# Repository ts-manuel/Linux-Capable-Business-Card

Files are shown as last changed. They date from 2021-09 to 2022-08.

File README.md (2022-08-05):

# Linux Capable business Card
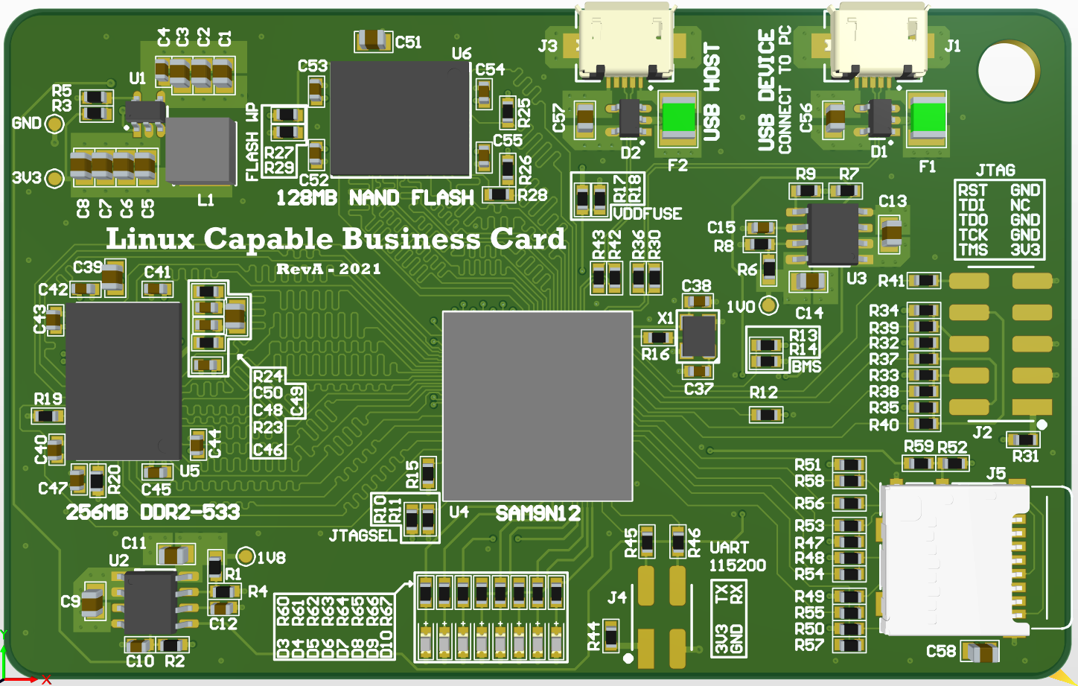
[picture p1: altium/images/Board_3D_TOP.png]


<!-- TABLE OF CONTENTS -->
<details open="open">
  <summary>Table of Contents</summary>
  <ol>
    <li><a href="#about-the-project">About The Project</a></li>
    <li><a href="#block-diagram">Block Diagram</a></li>
    <li><a href="#getting-started">Block Diagram</a></li>
  </ol>
</details>

<!-- ABOUT THE PROJECT -->
## About The Project
Business card sized computer capable of running Linux.

- Microchip AT91SAM9N12 microprocessor, ARM926 core running at 400MHz
- 256MB RAM DDR2-533
- 128MB of NAND FLASH
- micro SD-Card slot
- 8x LEDs

For more info check out the [project on hackaday.io](https://hackaday.io/project/181259-linux-capable-business-card)

<!-- BLOCK DIAGRAM -->
## Block Diagram
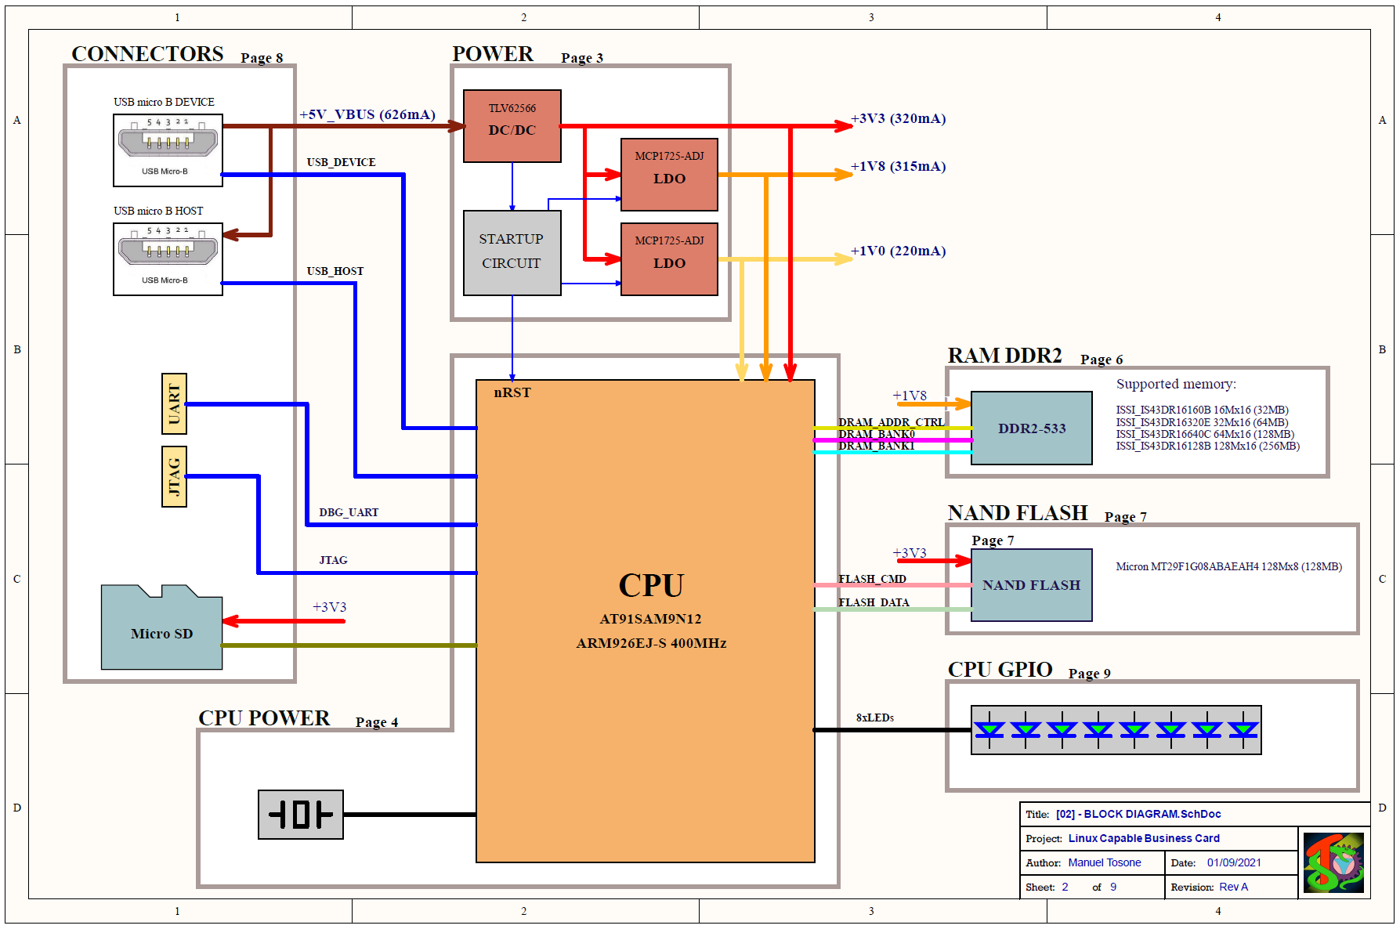
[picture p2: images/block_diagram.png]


<!-- GETTING STARTED -->
## Getting Started
### Getting the code
    git clone --recursive https://github.com/ts-manuel/Linux-Capable-Business-Card.git

### Compinig
    cd linux
    ./setup.sh
    ./build_sd_linux_dt.sh

### Buildroot Folder Structure
- buildroot/output/build/     where pakages are downloaded and builded
- buildroot/output/images/    where images are copied after building

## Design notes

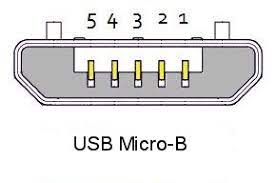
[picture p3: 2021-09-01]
altium/images/USB_micro_B.jpg

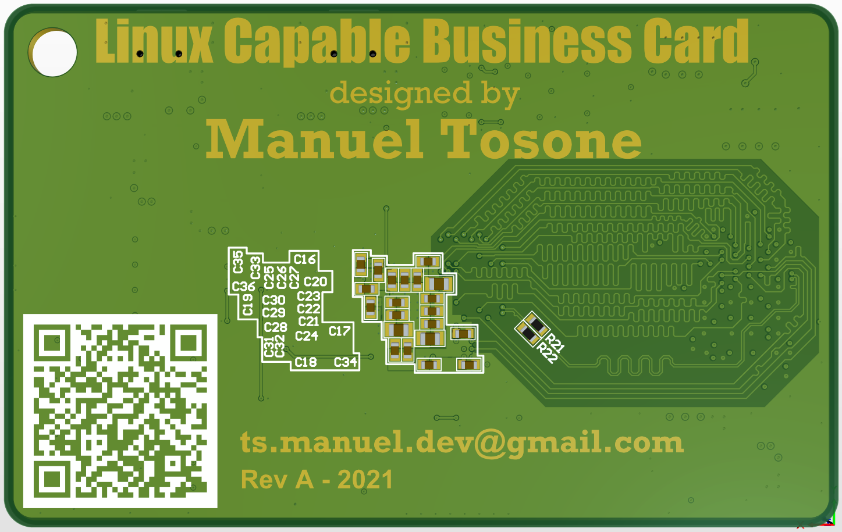
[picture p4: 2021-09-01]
altium/images/Board_3D_BOTTOM.png

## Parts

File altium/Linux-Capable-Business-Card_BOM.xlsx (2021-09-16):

Bill of Materials
Linux Capable Business Card - Rev A
# | Description | Supplier Part Number | Quantity | Designator | Value
1 | Multilayer Ceramic Capacitors MLCC - SMD/SMT WCAP-CSGP 4.7uF 0805 20% 16V MLCC | 710-885012107013 | 20 | C1, C2, C3, C5, C6, C7, C8, C9, C11, C13, C14, C20, C24, C28, C39, C49, C51, C56, C57, C58 | 4.7uF
2 | Multilayer Ceramic Capacitors MLCC - SMD/SMT 16V 0.1uF X7R 0603 20% | 80-C0603C104M4RAC | 34 | C4, C10, C16, C17, C18, C19, C21, C22, C23, C25, C26, C27, C29, C30, C31, C32, C33, C34, C35, C36, C40, C41, C42, C43, C44, C45, C46, C47, C48, C50, C52, C53, C54, C55 | 100nF
3 | Multilayer Ceramic Capacitors MLCC - SMD/SMT 50V 1000pF X7R 0603 5% | 80-C0603C102J5R | 2 | C12, C15 | 1nF
4 | Multilayer Ceramic Capacitors MLCC - SMD/SMT WCAP-CSGP 33pF 0603 5% 50V MLCC | 710-885012006054 | 2 | C37, C38 | 33pF
5 | ESD Suppressors / TVS Diodes 2 Ch TVS Diode Array 3.3V 6.0A 400mW | 621-D1213A-02SM-7 | 2 | D1, D2
6 | Standard LEDs - SMD WL-SMCW SMDMono TpVw Waterclr 0603 BrtGrn | 710-150060VS75000 | 8 | D3, D4, D5, D6, D7, D8, D9, D10 | Green
7 | Resettable Fuses - PPTC Fuse | 530-0ZCH0050FF2G | 2 | F1, F2 | 500mA
8 | USB Connectors Micro B, USB 2.0, 1.8 A, Right Angle, Surface Mount (SMT), USB Receptacle | 490-UJ2-MIBH-G-SMTTR | 2 | J1, J3
9 | Headers & Wire Housings ECONOSTIK HEADER DR VT SMT 2X5 | 649-1012938391002ALF | 1 | J2
10 | Headers & Wire Housings ECONOSTIK HEADER DR VT SMT 2X2 | 649-1012938390401ALF | 1 | J4
11 | Memory Card Connectors MICRO SD PUSH-PULL SMT 1.42MM HEIGHT | 538-104031-0811 | 1 | J5
12 | Fixed Inductors 5020 2.2uH 42mOhms +/-30%Tol 2900mA | 963-NRS5020T2R2NMGJ | 1 | L1 | 2.2uH
13 | Thin Film Resistors - SMD 1/10W 412K ohm 1% 50ppm | 603-RT0603FRE07412KL | 1 | R1 | 412K
14 | Thin Film Resistors - SMD 1/10W 120K ohm 1% 50ppm | 603-RT0603FRE07120KL | 18 | R2, R4, R5, R7, R8, R9, R25, R26, R32, R33, R34, R35, R47, R48, R49, R50, R51, R52 | 120K
15 | Thin Film Resistors - SMD 1/10W 536K ohm 1% 50ppm | 603-RT0603FRE07536KL | 1 | R3 | 536K
16 | Thin Film Resistors - SMD 1/10W 174K ohm 1% 50ppm | 603-RT0603FRE07174KL | 1 | R6 | 174K
17 | Thin Film Resistors - SMD 1/10W 330 ohm 1% 50ppm | 603-RT0603FRD07330RL | 25 | R10, R11, R12, R13, R14, R15, R16, R17, R18, R19, R20, R23, R24, R27, R29, R45, R46, R60, R61, R62, R63, R64, R65, R66, R67 | 330R
18 | Thin Film Resistors - SMD 1/10W 27 ohm 1% 50ppm | 603-RT0603DRD0727RL | 21 | R21, R22, R28, R30, R31, R36, R37, R38, R39, R40, R41, R42, R43, R44, R53, R54, R55, R56, R57, R58, R59 | 27R
19 | TLV6256x 1.5-A High Efficiency Step-Down Converters in SOT-23 5-Pin Package | 595-TLV62566DBVR | 1 | U1
20 | 500 mA, Low Voltage, Low Quiescent Current LDO Regulator | 579-MCP1725-ADJE/SN | 2 | U2, U3
21 | MPU ARM926EJ-S 400MHz | 556-AT91SAM9N12-CU | 1 | U4
22 | 256Mx8, 128Mx16 DDR2 DRAM | 870-3DR16128C-25DBLI | 1 | U5
23 | NAND Flash SLC 1G 128MX8 VFBGA-63 | 340-139663-TRAY | 1 | U6
24 | Crystals 12MHz 20ppm 18pF -20C +70C | 520-120-18-33-JEMT | 1 | X1 | 12 MHz

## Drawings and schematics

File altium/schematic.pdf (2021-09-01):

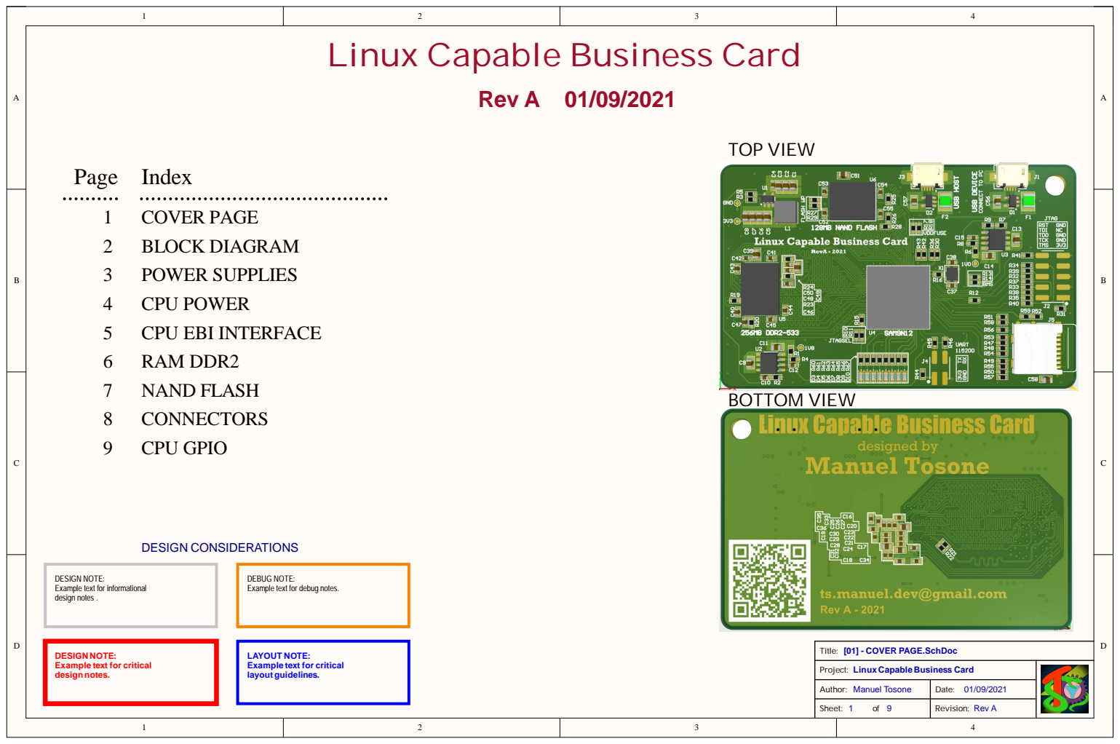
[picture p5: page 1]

Linux Capable Business Card

DESIGN NOTE:
Example text for informational
design notes .

DEBUG NOTE:
Example text for debug notes.

Example text for critical
design notes.

LAYOUT NOTE:
layout guidelines.

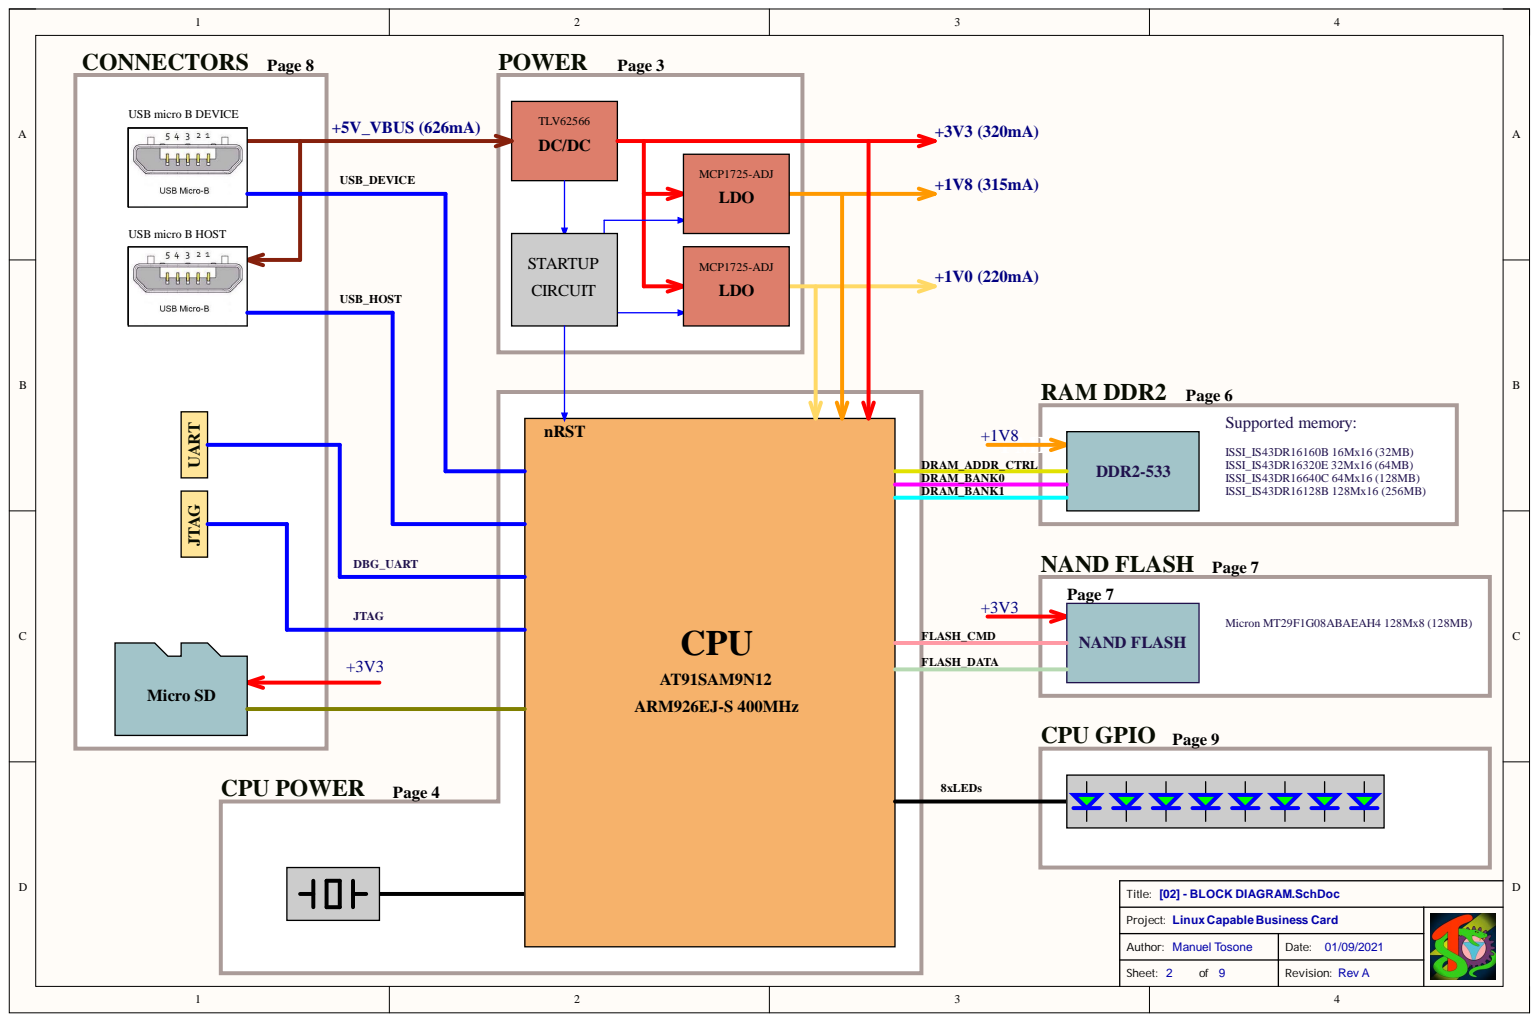
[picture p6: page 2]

USB_DEVICE

USB_HOST

DRAM_BANK0
DRAM_BANK1

Linux Capable Business Card

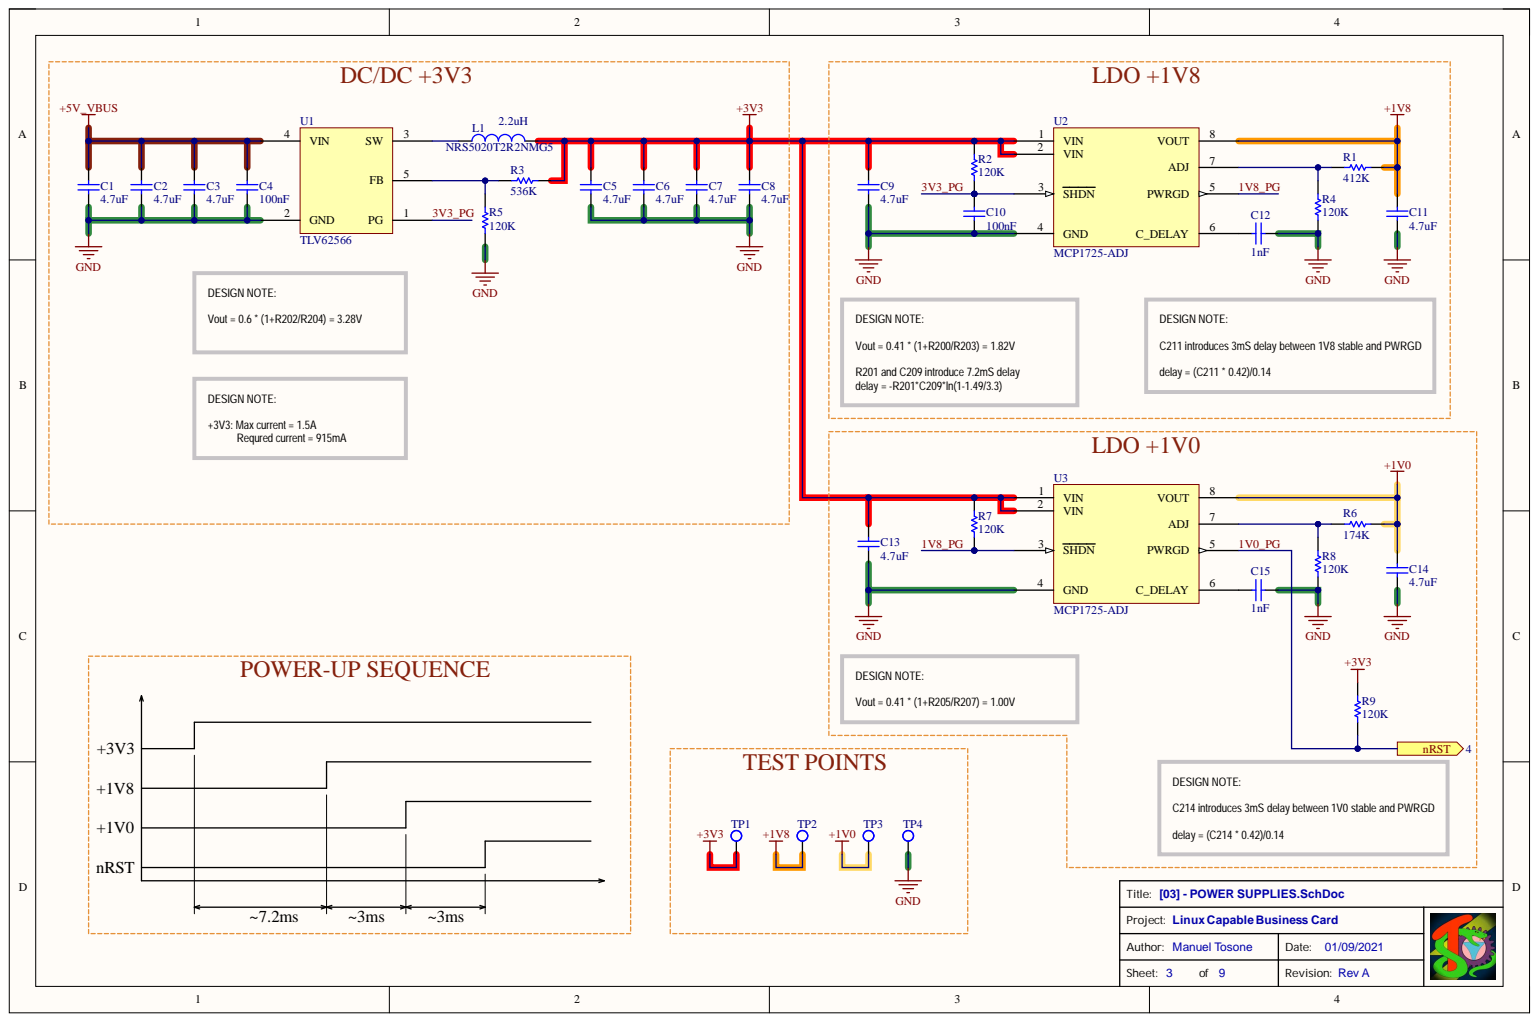
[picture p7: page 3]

C211 introduces 3mS delay between 1V8 stable and PWRGD

C214 introduces 3mS delay between 1V0 stable and PWRGD

Linux Capable Business Card

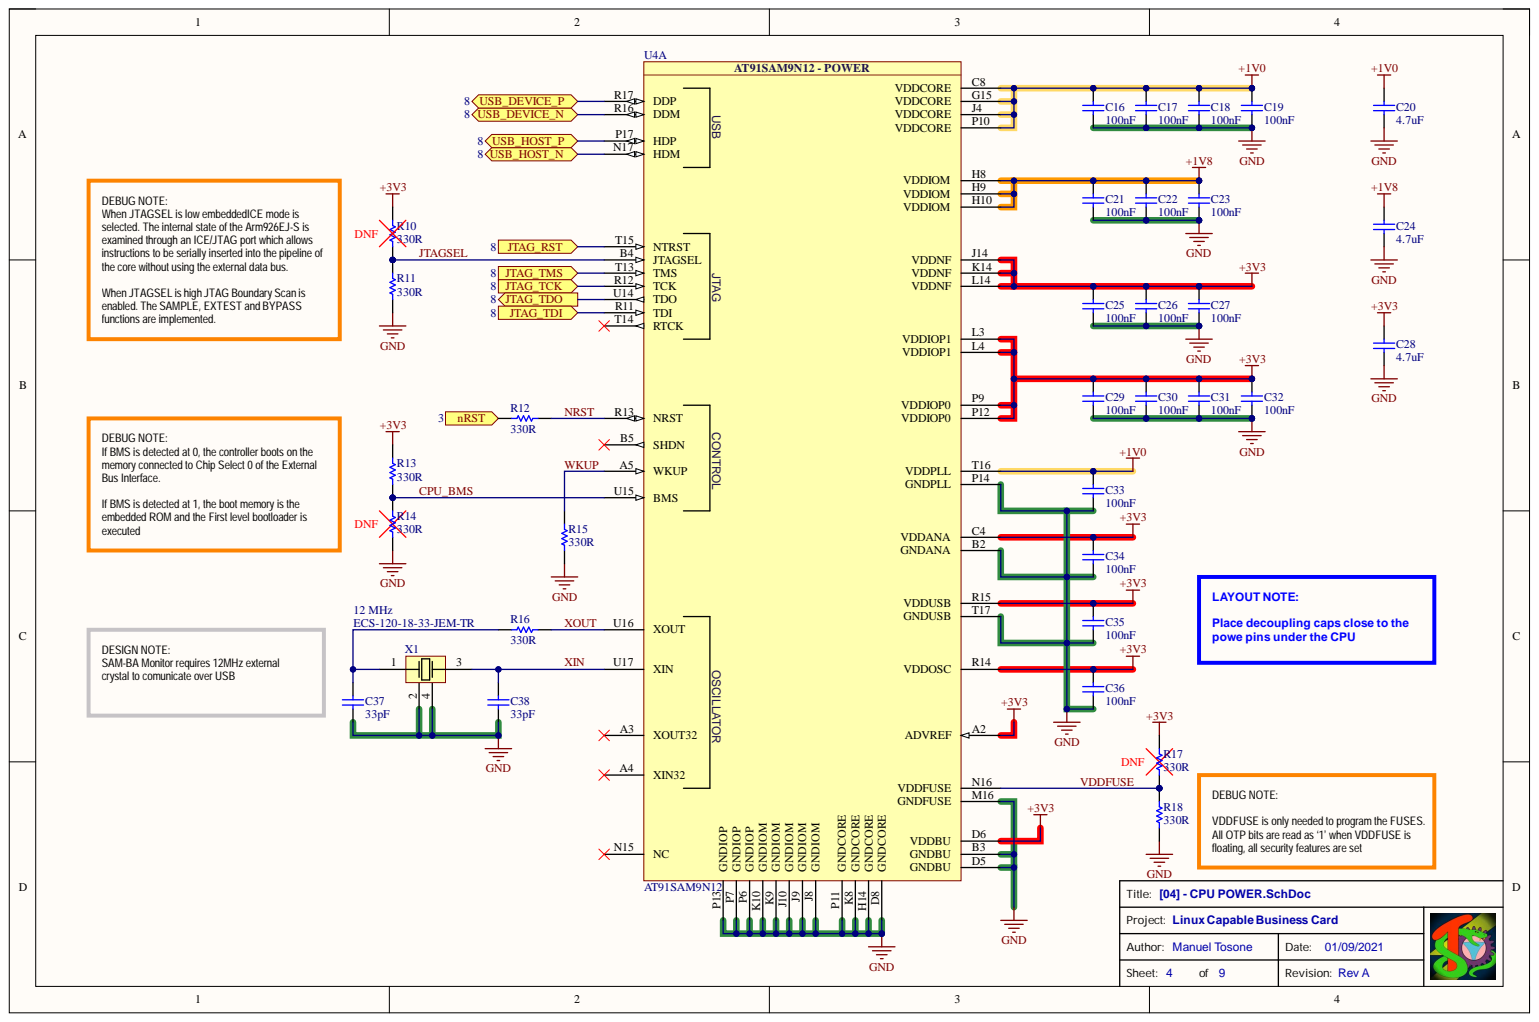
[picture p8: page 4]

USB JTAG OSCILLATOR CONTROL

DEBUG NOTE:
When JTAGSEL is low embeddedICE mode is
selected. The internal state of the Arm926EJ-S is
examined through an ICE/JTAG port which allows
instructions to be serially inserted into the pipeline of
the core without using the external data bus.

When JTAGSEL is high JTAG Boundary Scan is
enabled. The SAMPLE, EXTEST and BYPASS
functions are implemented.

If BMS is detected at 0, the controller boots on the
memory connected to Chip Select 0 of the External
Bus Interface.

If BMS is detected at 1, the boot memory is the
embedded ROM and the First level bootloader is
executed

Place decoupling caps close to the
powe pins under the CPU

DESIGN NOTE:
SAM-BA Monitor requires 12MHz external
crystal to comunicate over USB

GNDIOM J8 GNDIOM J9 GNDIOM J10 GNDIOM K9 GNDIOM K10

GNDCORE D8 GNDCORE H14 GNDCORE K8 GNDCORE P11

VDDFUSE is only needed to program the FUSES.
All OTP bits are read as ‘1’ when VDDFUSE is
floating, all security features are set

Linux Capable Business Card

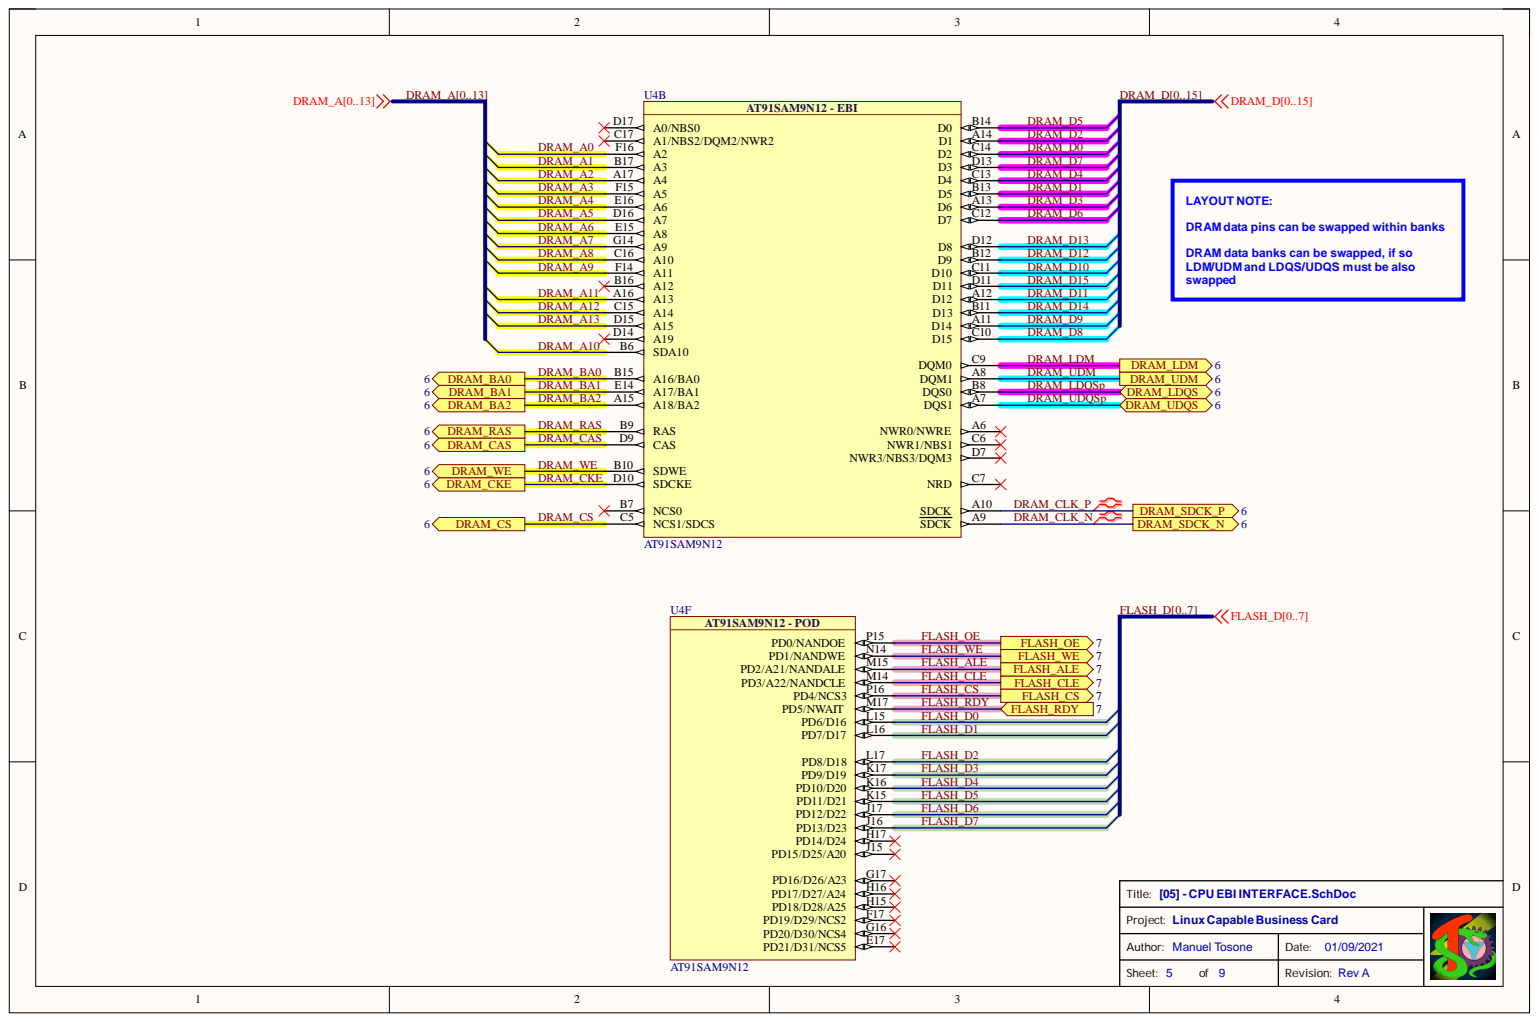
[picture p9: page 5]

DRAM data pins can be swapped within banks

DRAM data banks can be swapped, if so
LDM/UDM and LDQS/UDQS must be also
swapped

[05] - CPU EBI INTERFACE.SchDoc
Title:

Linux Capable Business Card

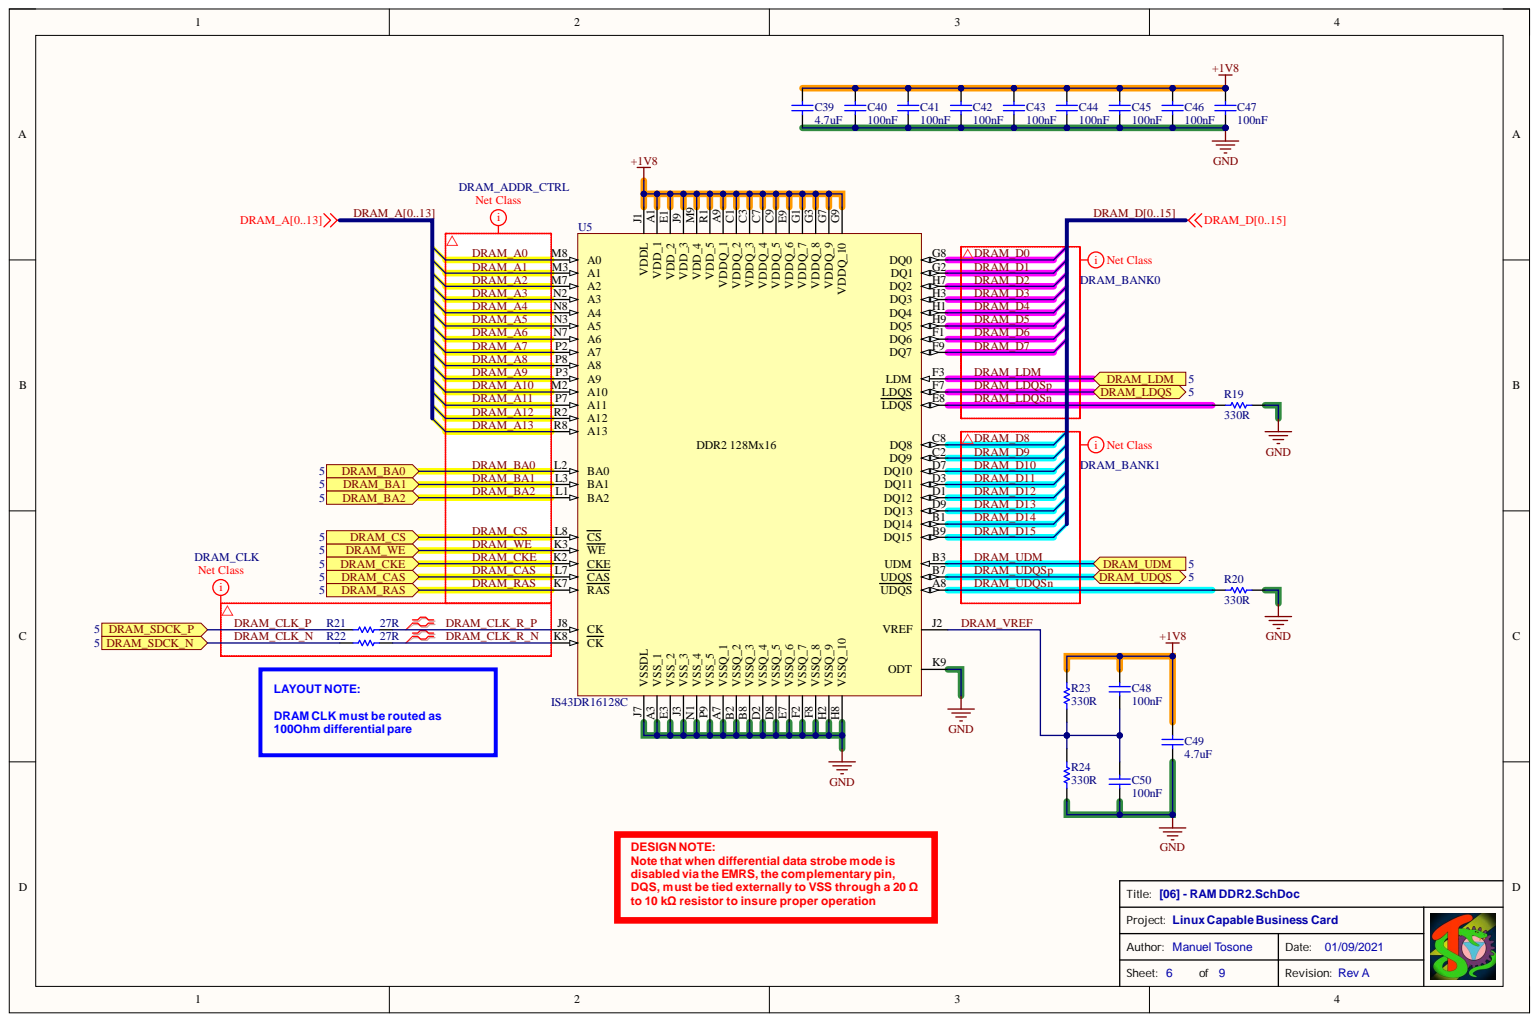
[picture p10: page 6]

DRAM_D0 DRAM_D1 DRAM_D2 DRAM_D3 DRAM_D4 DRAM_D5 DRAM_D6 DRAM_D7 DRAM_LDM DRAM_LDQSp DRAM_LDQSn

DRAM_A1 | A1 M3
DRAM_A2 | A2 M7
DRAM_A3 | A3 N2
DRAM_A4 | A4 N8
DRAM_A5 | A5 N3
DRAM_A6 | A6 N7
DRAM_A7 | A7 P2
DRAM_A8 | A8 P8
DRAM_A9 | A9 P3
DRAM_A10 | A10 M2
DRAM_A11 | A11 P7
DRAM_A12 | A12 R2
DRAM_A13 | A13 R8

DRAM CLK must be routed as

DESIGN NOTE:
Note that when differential data strobe mode is
disabled via the EMRS, the complementary pin,
DQS, must be tied externally to VSS through a 20 Ω
to 10 kΩ resistor to insure proper operation

Linux Capable Business Card

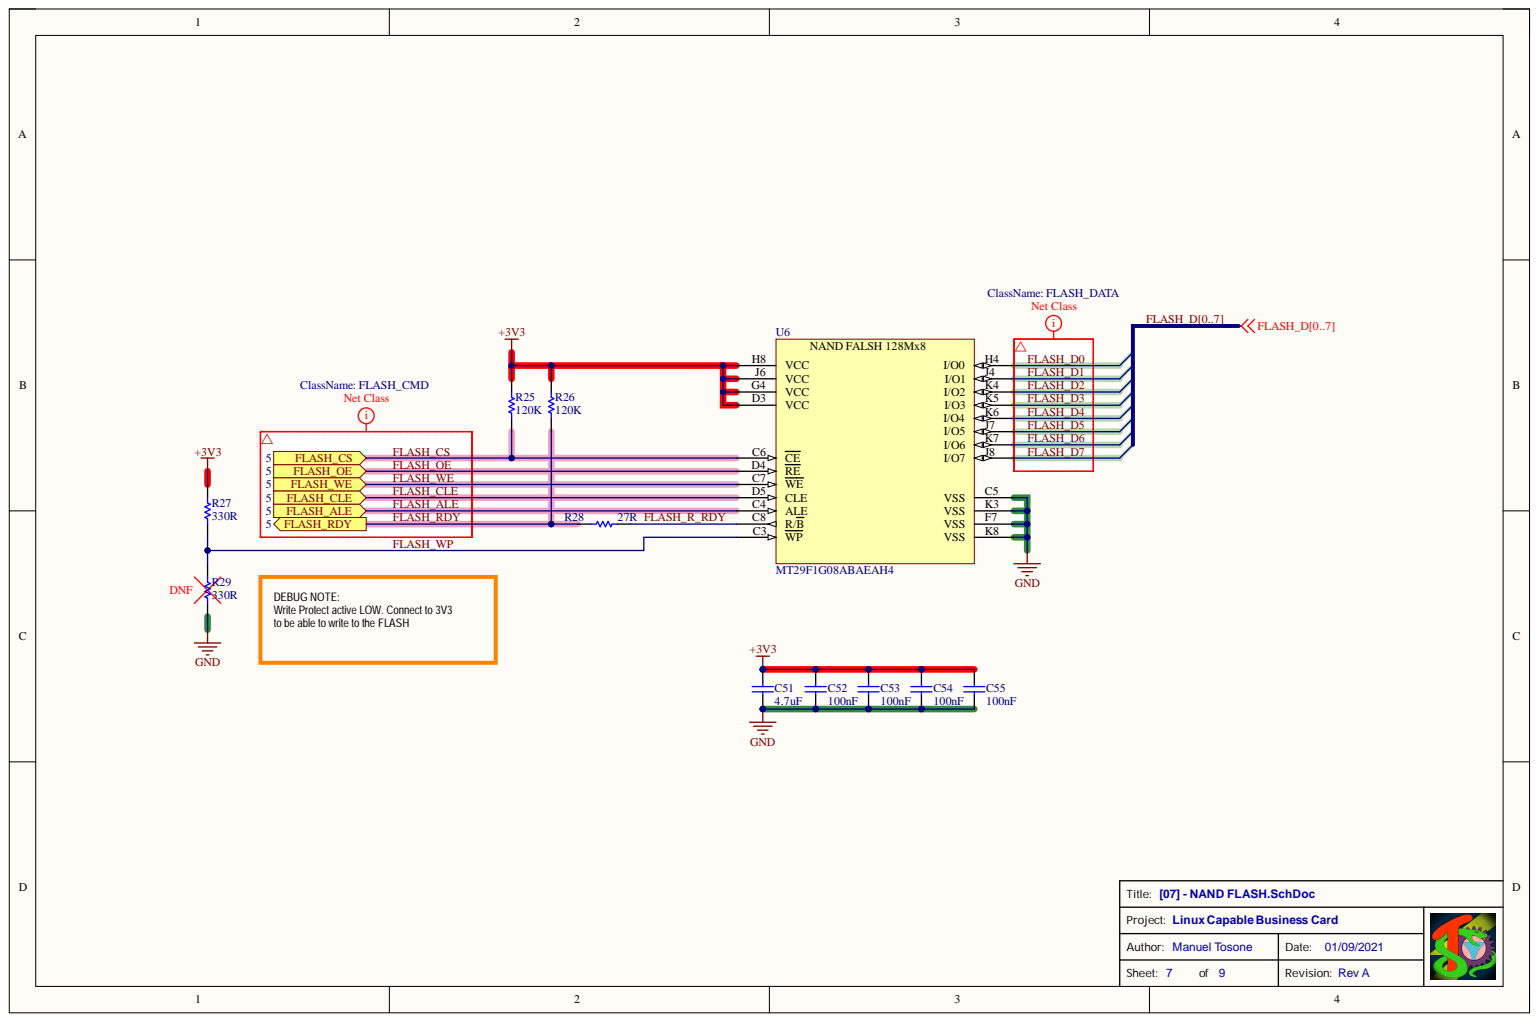
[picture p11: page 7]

DEBUG NOTE:
Write Protect active LOW. Connect to 3V3
to be able to write to the FLASH

Linux Capable Business Card

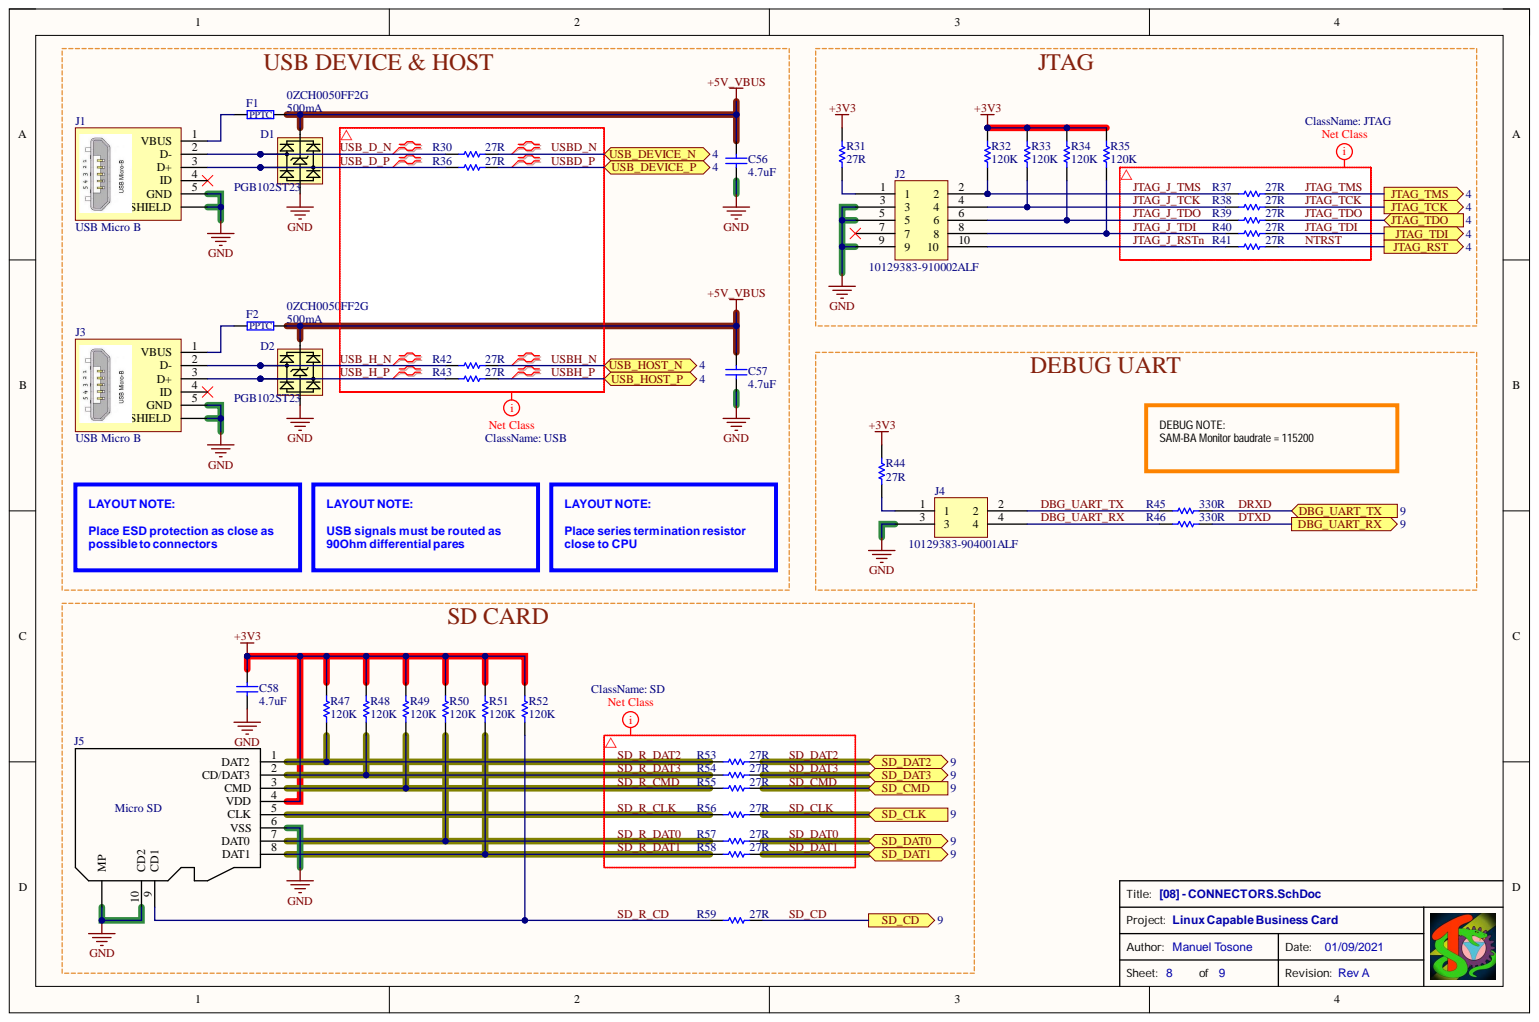
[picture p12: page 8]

DEBUG NOTE:
SAM-BA Monitor baudrate = 115200

Place ESD protection as close as
possible to connectors

USB signals must be routed as
90Ohm differential pares

Place series termination resistor
close to CPU

Linux Capable Business Card

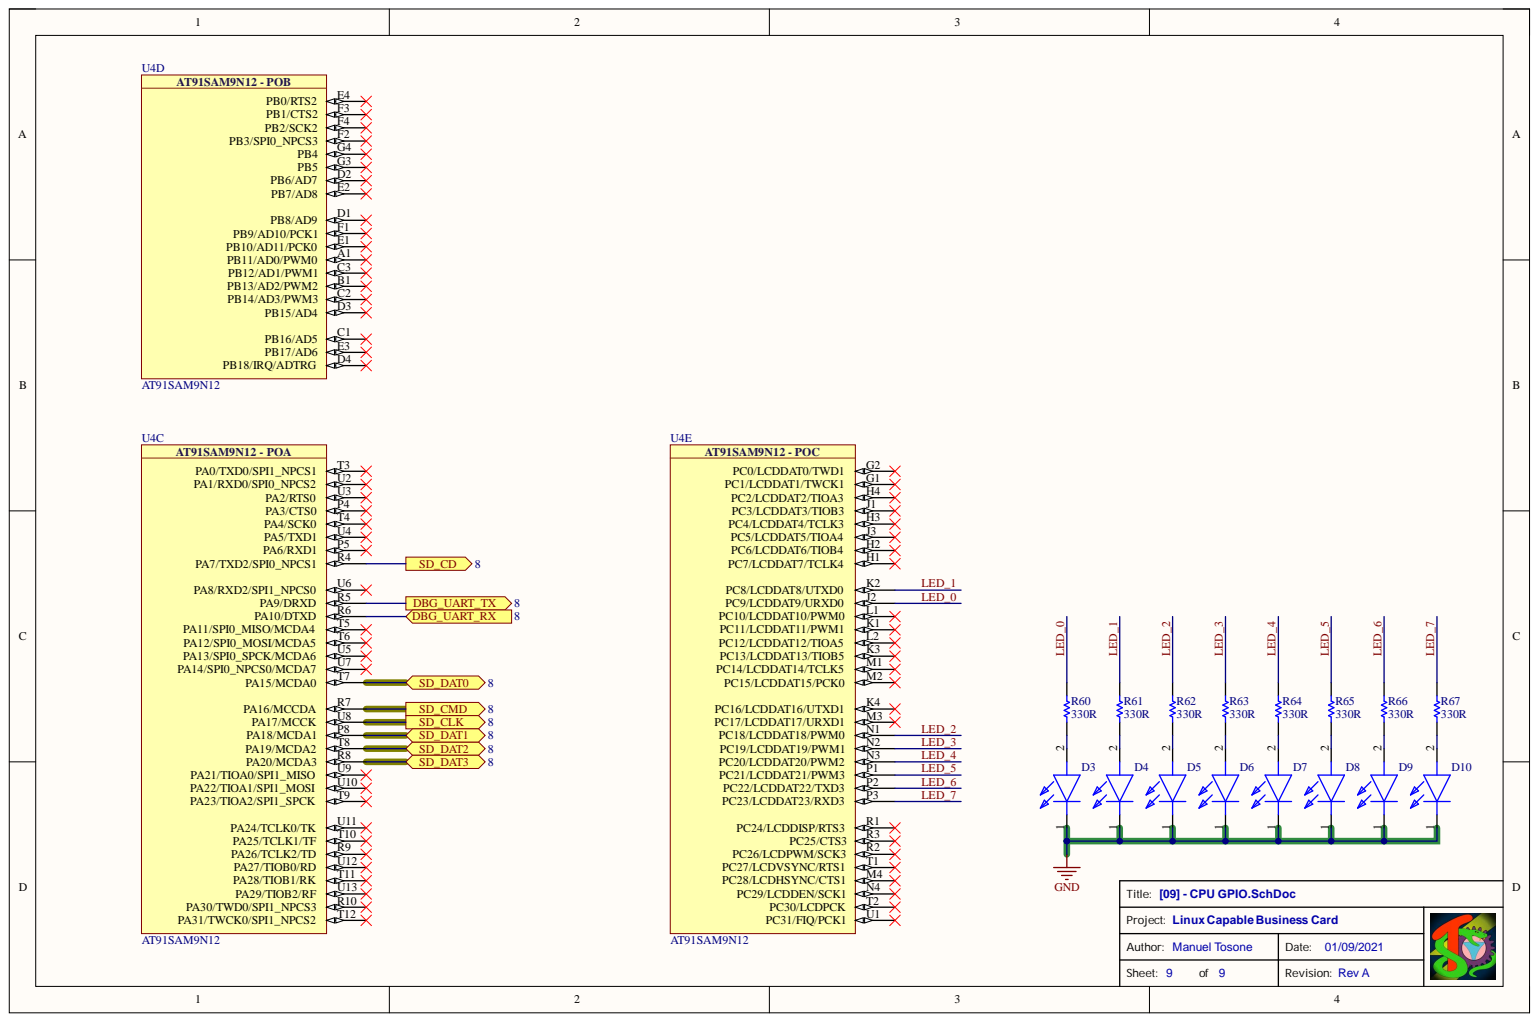
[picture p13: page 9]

Linux Capable Business Card

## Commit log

2021-09-06 Added DDR2 length calculator spreadsheet
    [DDR2 length calculator.xlsx]
2021-09-16 Added buildroot 2018.11
    Linux boots from SD card
    clock: CPU 300MHz, RAM 100MHz
    [Linux-Capable-Business-Card_BOM.xlsx]
2021-09-19 Serial port over USB using Gadget framework
    Raised clock frequencies:
    clock: CPU 399MHz, RAM 133Mhz
2022-08-05 Fixed designators in schematic notes
    [Linux-Capable-Business-Card.PrjPcb, [03] - POWER SUPPLIES.SchDoc]
2022-08-05 Renamed schematic and gerbers
